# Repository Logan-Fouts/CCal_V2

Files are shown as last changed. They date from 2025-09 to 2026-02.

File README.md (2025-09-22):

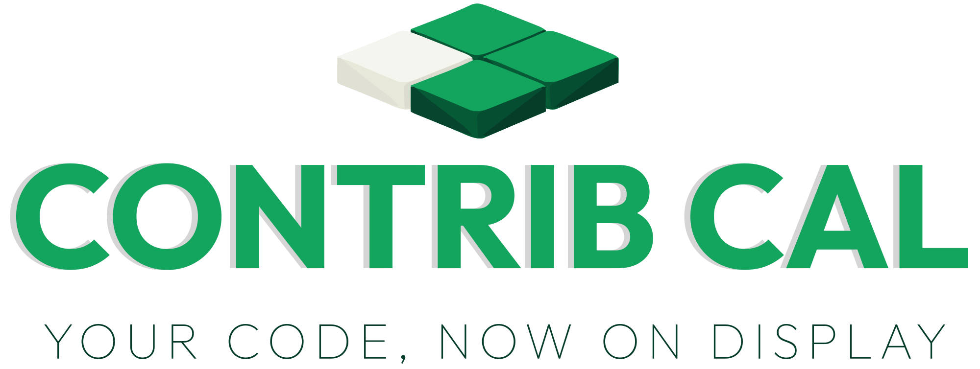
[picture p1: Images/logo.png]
  

Contrib Cal v2 is a contribution tracker built around a Raspberry Pi Zero W. It shows your GitHub activity using LEDs and includes a web interface for easy setup and control. The project is open, hackable, and designed for anyone interested in building their own contribution calendar.

Take a look at my [website!](https://www.contrib-cal.com/)

## Availability
This will soon be available to purchase as a kit from sellers like Elecrow and Tindie!

---

## Sponsored by PCBWay

PCBWay provided the PCBs for this project. They offer PCB fabrication and 3D printing with quick turnaround and worldwide shipping.  
[Check out PCBWay.com](https://pcbway.com) if you want to order your own boards.

---

## Features

- **GitHub Sync:** Shows your GitHub activity on an LED matrix.
- **Weather Animations:** Displays weather effects and temperature.
- **Tailscale:** Optionally connect your Pi to a Tailscale network.
- **Syncthing:** Optionally run a Syncthing node for file sync.
- **Pi-hole:** Optionally run Pi-hole for ad blocking.
- **Customizable:** Animations and logic are written in Python.
- **DIY Build:** Use a 3D-printed case and a custom PCB LED matrix.
- **Web Interface:** Configure settings and add-ons from your browser.

---

## Hardware Files

- **3D Print Files:** Available on Thingiverse at [https://www.thingiverse.com/thing:7136260](https://www.thingiverse.com/thing:7136260)
- **KiCad PCB Design Files:** Located in the `KiCad` folder in this repository.
- **PCBWay Order Zip:** The `PCBWay file.zip` in this repo can be uploaded directly to PCBWay—just drag and drop it on their site to order your board.

---

## Web Interface

You can manage most settings and add-ons through a simple web page hosted on the Pi.

---

## Build Guide

- **LEDs:** 28x SMD5050 RGB addressable LEDs (SK6812 or similar)
- **Microcontroller:** 1x Raspberry Pi Zero W (Pi Zero 2 W may work, but not tested)
- **Power Adapter:** 5V step down buck convertor and usbc breakout board
- **PCB:** Can be ordered using the `PCBWay file.zip` mentioned previosly

You can substitute

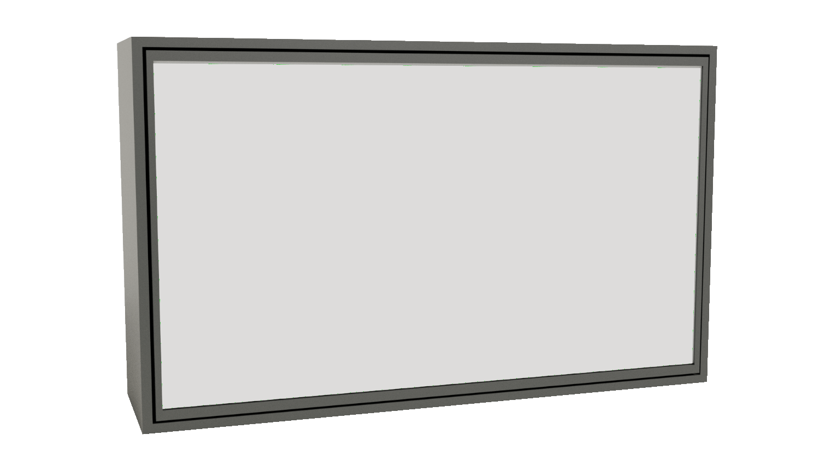
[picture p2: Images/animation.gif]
Contrib Cal in Action
  

---

## Getting Started

See [GettingStarted.md](./GettingStarted.md) for step-by-step instructions on flashing, setup, and configuration.

---

## Contributing

Pull requests and suggestions are welcome.  
If you run into issues or have ideas, feel free to open an issue on GitHub.

---

## Note on GitHub API Real-Time Updates

Contrib Cal v2 displays your GitHub activity as close to real-time as possible using the GitHub API. However, there may be delays in showing the most recent events due to how quickly GitHub updates and provides new event data. This is a limitation of the GitHub API itself and not an issue with this project's implementation.

---

Thanks for checking out Contrib Cal, Feel free to open up PRs!

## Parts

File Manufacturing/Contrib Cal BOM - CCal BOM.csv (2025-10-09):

Manufacturer Part Number | Qty | Original | Description | Purchase link
Main PCB | 1 | y | Main PCB | Produced by Elecrow.
TPS563201. | 1 | y | Buck Converter (Step-Down) WeAct Studio. Input: 5-36V, Output: 3.3V/2A | https://www.aliexpress.com/item/1005009680381342.html
Raspberry Pi Zero W | 1 | y | Raspberry Pi Zero W | https://www.alibaba.com/product-detail/Ras-Pberry-Pi-zero-W-Development_1601238061099.html
WS2812B (or SK6812) 5050 | 30 | n | SMD RGB LED WS2812B (or SK6812) 5050 package. IC built-in, 4-pin. | https://www.alibaba.com/product-detail/Promotion-Wholesale-IC-Buit-in-4pin_60610111946.html
Module-F55 | 1 | y | USB-C Breakout Board | https://www.alibaba.com/product-detail/YIXINTAI-USB-TYPE-C-conversion-board_1601234419325.html
Hookup Wire | 5 | n | ~12cm each. 28 AWG stranded wire is recommended for flexibility. Colors: Recommended (Red: 5V, Black: GND, other colors for data). | Elecrow to source.
Screw (M3 x 12mm) | 4 | n | Phillips, flat head. For securing the PCB assembly to the case. | Elecrow to source.
Heated Insert (M3) | 4 | n | Brass inserts to be melted into the 3D printed case for the M3 screws. | Elecrow to source.
Screw (M1.7) | 4 | n | Phillips, flat head. For mounting the Raspberry Pi Zero. | Elecrow to source.
Screw (M2.5) | 6 | n | Phillips, flat head. (Likely for the buck converter or other components). | Elecrow to source.
Screw (M2) | 2 | n | Phillips, flat head. (Likely for the USB-C breakout). | Elecrow to source.
Diffusion Paper / Screen | 1 | n | A5 size (210 x 148 mm), ~120 GSM weight. | https://www.alibaba.com/product-detail/Wholesale-120-g-350-g-C1S_1601258869224.html
microSD Card | 1 | n | 16GB+, Class 10. Major Brand Recommended (SanDisk, Samsung, Kingston). | Elecrow source. Do not source from random marketplaces due to high failure rate risk. Buy from a reputable electronics or computer store.
3D Printed Stencil Cut out | 1 | n | Print Settings: 0.2mm layers. | Produced by Elecrow as part of the PCB/Assembly order.
3D Printed Back Case | 1 | y | Print Settings: 0.2mm layers, Fuzzy Skin (Point Dist: 0.1mm, Thickness: 0.1mm on all walls). | Produced by Elecrow as part of the PCB/Assembly order.
3D Printed Front Face | 1 | y | Print Settings: 0.2mm layers, Fuzzy Skin, Enable Ironing for a smooth top surface. | Produced by Elecrow as part of the PCB/Assembly order.

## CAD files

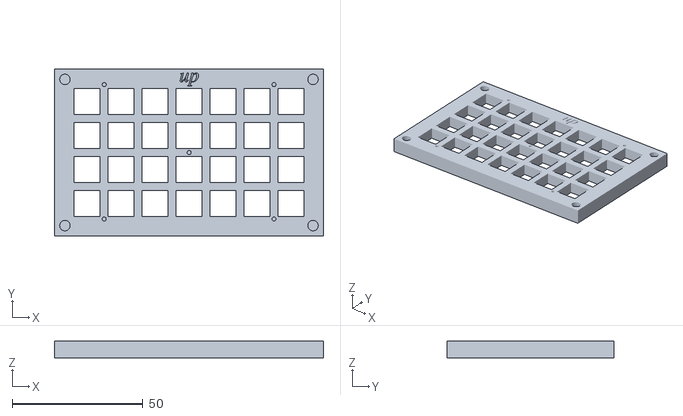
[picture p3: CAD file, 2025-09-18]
Hardware/FreeCAD/3d Objects/CCal v2-Face.obj
103.0 x 64.0 x 6.50

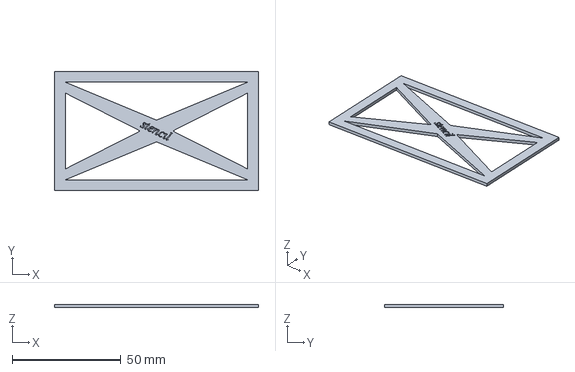
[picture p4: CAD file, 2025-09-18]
Hardware/FreeCAD/CCal v2.FCStd
94.0 x 55.0 x 1.50 mm

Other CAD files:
Hardware/FreeCAD/3d Objects/CCal v2-Cut Out Stencil v2.obj

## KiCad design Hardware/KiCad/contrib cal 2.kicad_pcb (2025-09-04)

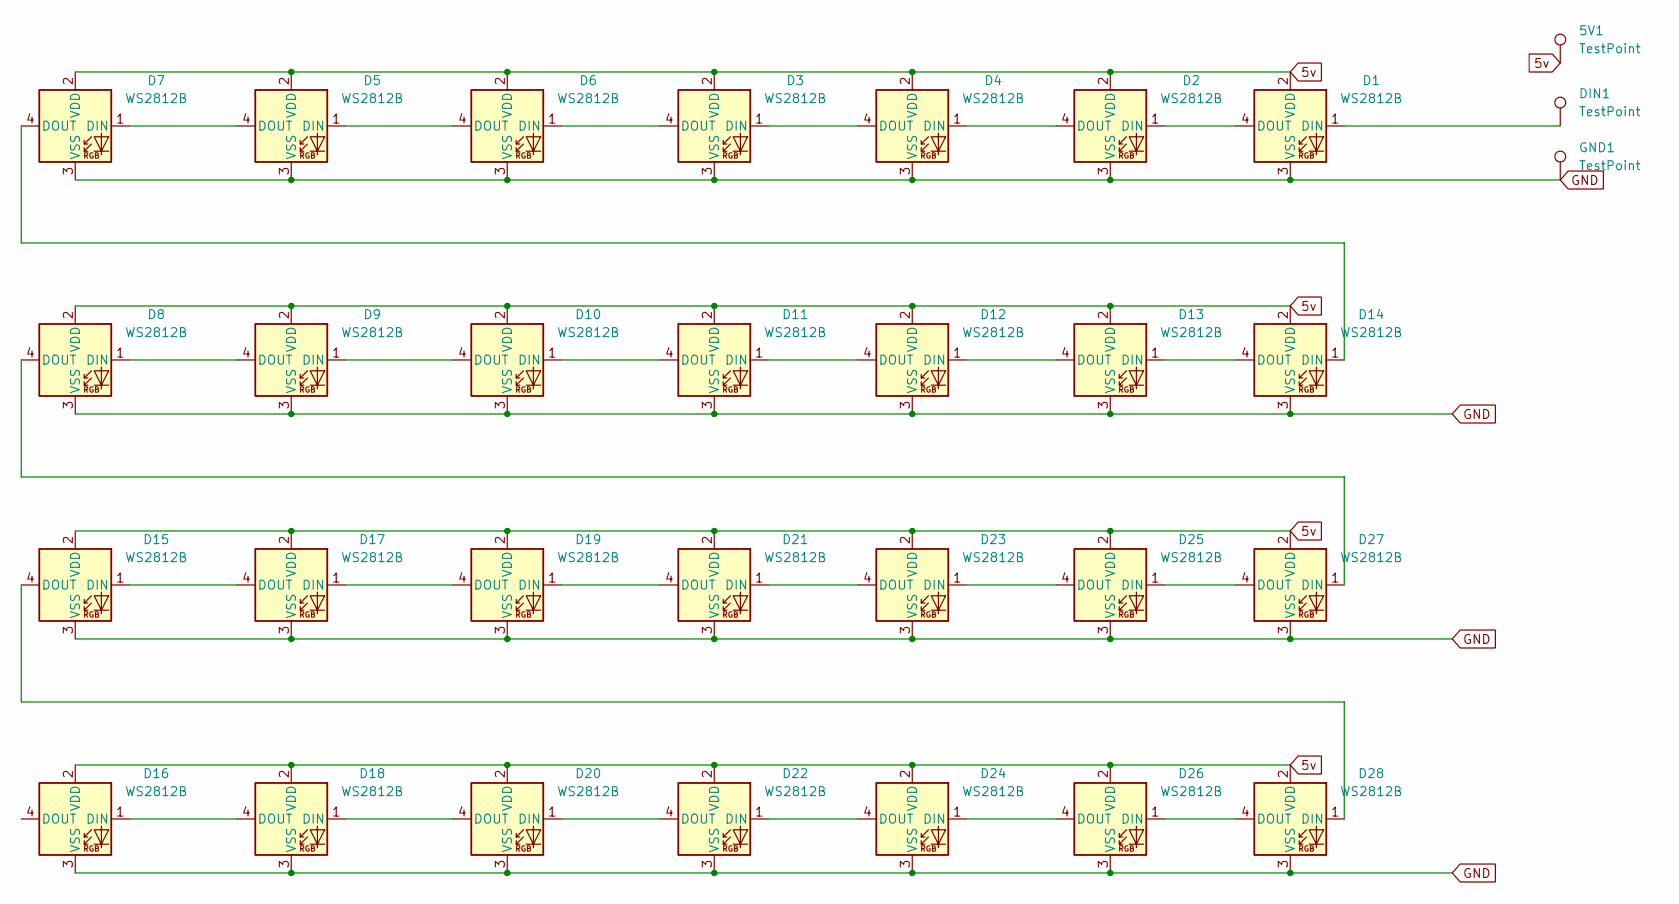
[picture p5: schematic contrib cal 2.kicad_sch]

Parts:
5V1: TestPoint; TestPoint_Pad_3.0x3.0mm
D1, D2, D3, D4, D5, D6, D7, D8, D9, D10, D11, D12, D13, D14, D15, D16, D17, D18, D19, D20, D21, D22, D23, D24, D25, D26, D27, D28: WS2812B; WS2812
DIN1: TestPoint; TestPoint_Pad_3.0x3.0mm
GND1: TestPoint; TestPoint_Pad_3.0x3.0mm

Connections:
5v: 5V1.1, D1.2 (VDD), D2.2 (VDD), D3.2 (VDD), D4.2 (VDD), D5.2 (VDD), D6.2 (VDD), D7.2 (VDD), D8.2 (VDD), D9.2 (VDD), D10.2 (VDD), D11.2 (VDD), D12.2 (VDD), D13.2 (VDD), D14.2 (VDD), D15.2 (VDD), D16.2 (VDD), D17.2 (VDD), D18.2 (VDD), D19.2 (VDD), D20.2 (VDD), D21.2 (VDD), D22.2 (VDD), D23.2 (VDD), D24.2 (VDD), D25.2 (VDD), D26.2 (VDD), D27.2 (VDD), D28.2 (VDD)
GND: D1.3 (VSS), D2.3 (VSS), D3.3 (VSS), D4.3 (VSS), D5.3 (VSS), D6.3 (VSS), D7.3 (VSS), D8.3 (VSS), D9.3 (VSS), D10.3 (VSS), D11.3 (VSS), D12.3 (VSS), D13.3 (VSS), D14.3 (VSS), D15.3 (VSS), D16.3 (VSS), D17.3 (VSS), D18.3 (VSS), D19.3 (VSS), D20.3 (VSS), D21.3 (VSS), D22.3 (VSS), D23.3 (VSS), D24.3 (VSS), D25.3 (VSS), D26.3 (VSS), D27.3 (VSS), D28.3 (VSS), GND1.1
unnamed: D1.1 (DIN), DIN1.1
unnamed: D1.4 (DOUT), D2.1 (DIN)
unnamed: D2.4 (DOUT), D4.1 (DIN)
unnamed: D3.1 (DIN), D4.4 (DOUT)
unnamed: D3.4 (DOUT), D6.1 (DIN)
unnamed: D5.1 (DIN), D6.4 (DOUT)
unnamed: D5.4 (DOUT), D7.1 (DIN)
unnamed: D8.1 (DIN), D9.4 (DOUT)
unnamed: D10.1 (DIN), D11.4 (DOUT)
unnamed: D9.1 (DIN), D10.4 (DOUT)
unnamed: D11.1 (DIN), D12.4 (DOUT)
unnamed: D12.1 (DIN), D13.4 (DOUT)
unnamed: D13.1 (DIN), D14.4 (DOUT)
unnamed: D7.4 (DOUT), D14.1 (DIN)
unnamed: D15.1 (DIN), D17.4 (DOUT)
unnamed: D15.4 (DOUT), D28.1 (DIN)
unnamed: D16.1 (DIN), D18.4 (DOUT)
unnamed: D17.1 (DIN), D19.4 (DOUT)
unnamed: D18.1 (DIN), D20.4 (DOUT)
unnamed: D19.1 (DIN), D21.4 (DOUT)
unnamed: D20.1 (DIN), D22.4 (DOUT)
unnamed: D21.1 (DIN), D23.4 (DOUT)
unnamed: D22.1 (DIN), D24.4 (DOUT)
unnamed: D23.1 (DIN), D25.4 (DOUT)
unnamed: D24.1 (DIN), D26.4 (DOUT)
unnamed: D25.1 (DIN), D27.4 (DOUT)
unnamed: D26.1 (DIN), D28.4 (DOUT)
unnamed: D8.4 (DOUT), D27.1 (DIN)

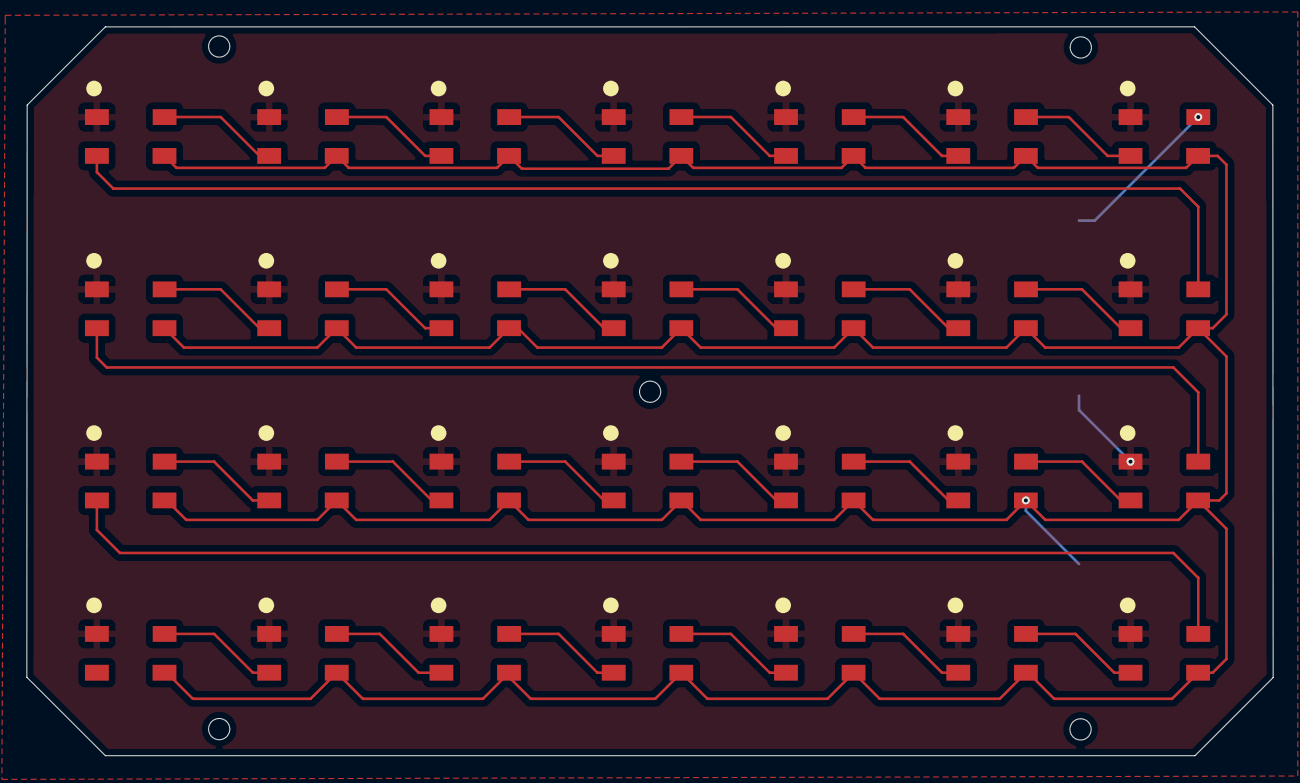
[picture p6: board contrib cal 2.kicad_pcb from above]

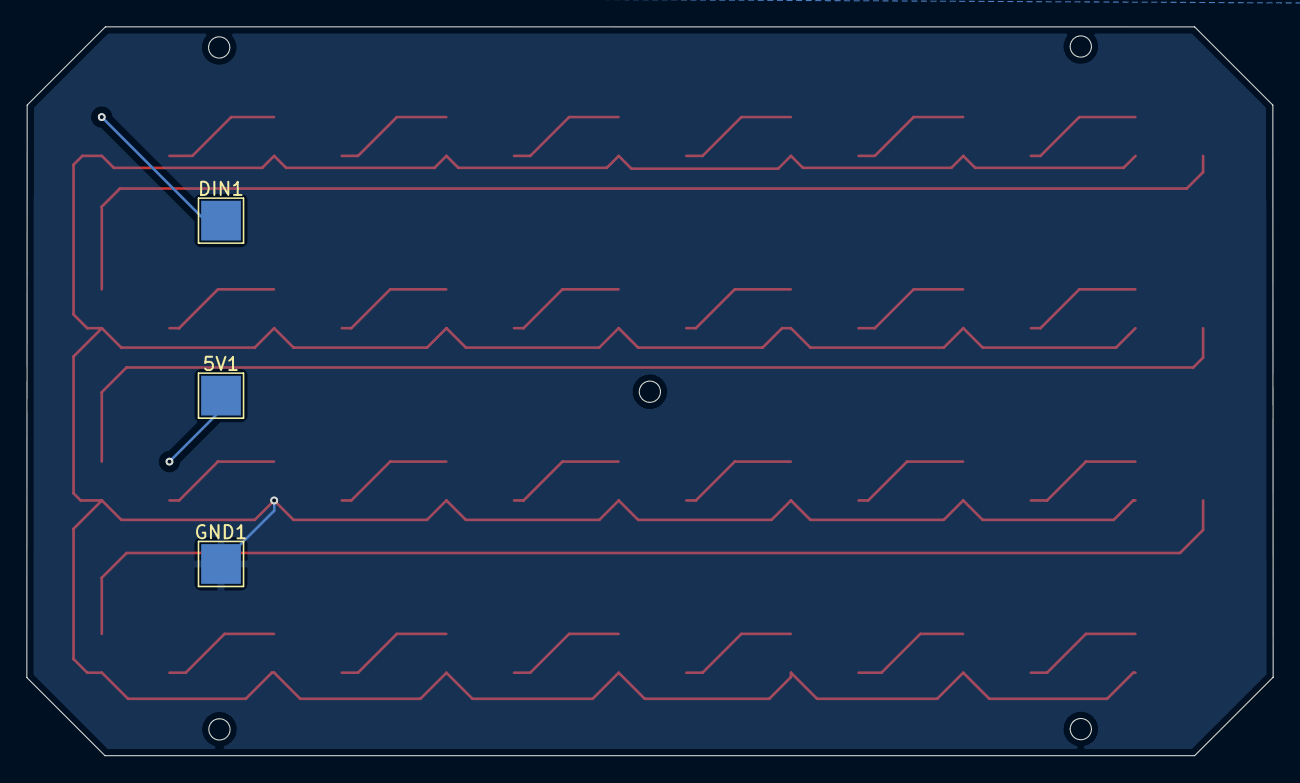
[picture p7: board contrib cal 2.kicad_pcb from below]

Board: 2 copper layers, 94.1 x 55.0 mm, 31 parts (3 on the bottom side), 30 nets.

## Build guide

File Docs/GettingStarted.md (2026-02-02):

# Getting Started with Daily Grid

This guide will help you set up your Daily Grid.  
Follow the steps below to get everything working.

---

## Quick Start (Prebuilt Image)

1. **Prepare Your SD Card**
    - Insert the micro SD card into your computer.
    - Open the **boot** partition on the SD card and locate the `wpa_supplicant.conf` file (if it does not exist, create it in the root of the boot partition).
    - Update these fields:
        - `country` — your country code (like US, GB, DE)
        - `ssid` — your WiFi network name
        - `psk` — your WiFi password

2. **Insert & Power On**
    - Safely eject the SD card and put it in your Pi Zero.
    - Power on the Pi and wait for it to connect to your network.
    - **Note:** The first boot can take a while as the Pi sets itself up and connects to WiFi. Be patient—it may take several minutes.
    - *(Tip: You can use the `ping` command to check when the device is online.)*

3. **Access the Web Interface**
    - Open a browser and go to:  
      `http://<device-ip>:8080`
    - Replace `<device-ip>` with your Pi's IP address.

4. **Configure Settings**
    - Log in with the default credentials below.
    - Use the web interface to finish setup.

---

### Default WebGUI Credentials

- **Username:** `dailygrid`
- **Password:** `raspberry`

---

### Set Your Own WebGUI Login

To set your own username and password for the WebGUI, run this command (replace `yourusername` and `yourpassword`):
```sh
echo -e "DAILYGRID_WEBGUI_USER=yourusername\nDAILYGRID_WEBGUI_PASS=yourpassword" > ~/Daily-Grid/WebGUI/.env
```
*Or just edit the file with whatever text editor you want*
You'll need to use sudo since the files are owned by the root user. You of course can modify the permisions so you dont need to use sudo.
```sh
sudo vim ~/Daily-Grid/WebGUI/.env
```

---

## Build Your Own

If you want to build Daily Grid yourself:

1. **Flash Raspbian**
    - Install the latest Raspbian OS on a Pi Zero W (using Pi Imager is recommended).

**Recommended:**  
Use [Raspberry Pi Imager](https://www.raspberrypi.com/software/) for the easiest setup.  
- Open Raspberry Pi Imager and select the OS (choose "Raspberry Pi OS Lite (32-bit)" or similar).
- Click the gear icon (⚙️) to set your username, password, WiFi info, and enable SSH.
- Write the image to your micro SD card.
- *(If you’re not using Pi Imager, you can manually edit or create the `wpa_supplicant.conf` file in the boot partition for WiFi setup.)* Take a look at step one from teh quick start above for more help.

2. **SSH into the pi**
    - Wait for it to connect to your wifi then ssh into the pi using the command below *(replace usrename and ip)*:
    ```sh
    ssh username@ip
    ```

3. **Download & Run the Setup Script**
    ```sh
    sudo curl https://raw.githubusercontent.com/Logan-Fouts/Daily-Grid/refs/heads/main/setup.sh | sh
    ```
    Or if you are having issues with the interactive shell then use the steps here:
    1. ```sh
       sudo wget https://raw.githubusercontent.com/Logan-Fouts/Daily-Grid/refs/heads/main/setup.sh
       ```
    2. ```sh
       sudo chmod +x setup.sh
       ```
    3. ```sh
       sudo ./setup.sh
       ```
    - **Note:** This command will take quite a while to run, as it installs all dependencies and sets up the system.

5. **Source the updated bashrc**
    - Either exit the ssh session then rejoin or run:
    ```sh
    source ~/.bashrc
    ```

4. **Configure Your Device**
    - Follow the Quick Start steps above starting at step 3.
    - If you enable Pi-hole during setup, the only thing you need to do is click through the Pi-hole options when prompted.

---

### Example `config.json`

Here’s an example configuration file you can use or edit:

```json
{
   "GITHUB_USERNAME": "Logan-Fouts",
   "GITHUB_TOKEN": "*",
   "STARTUP_ANIMATION": 3,
   "TAILSCALE_ENABLE": true,
   "PIHOLE_ENABLE": true,
   "SYNCTHING_ENABLE": true,
   "LAST_EVENT_ID": "*",
   "OPENWEATHERMAP_API_KEY": "*",
   "WEATHER_LAT": 0.000,
   "WEATHER_LON": 0.000,
   "BRIGHTNESS": 80
}
```

---

## Tips

- **Change your WebGUI password** after your first login.
- Make sure your Pi and your computer are on the same network.
- If you need help, open an issue on the [GitHub repository](https://github.com/Logan-Fouts/Daily-Grid).
- Be patient during the first boot and setup—some steps can take several minutes.

---

Thanks for trying out Daily Grid! Enjoy your new Activity Calendar.

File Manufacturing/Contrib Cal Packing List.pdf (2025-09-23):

# Packaging List: Contrib Cal V2 DIY Kit

## Instructions:

Place all items listed below into one main kit box. Small components (screws, inserts, LEDs) should be placed in separate, small bags. Electrostatic-sensitive items (PCB, Pi Zero, microSD) should be placed in anti-static bags.

Item | Component Name | Quantity | Packaging Notes
1 | Custom Main PCB | 1 Place in Anti-Static Bag
2 | Buck Converter (Step-Down) | 1 | Place in Anti-Static Bag or its original packaging.
3 | Raspberry Pi Zero W | 1 Place in Anti-Static Bag
4 | SMD RGB LED (WS2812B / SK6812) | 30 Bag all 30 LEDs together.
5 | USB-C Breakout Board | 1 | Place in Anti-Static Bag or its original packaging.
6 | Hook-up Wire (~12cm, 28 AWG) | 5 Bundle wires together or place in a small bag.
7 | 3D Printed Back Case | 1
8 | 3D Printed Front Face | 1
9 | Screw (M3 x 12mm) | 4 Place in a small bag labeled M3x12mm Screws
10 | Heated Insert (M3, Brass) | 4 Place in a small bag labeled M3 Inserts
11 | Screw (M1.7) | 4 Place in a small bag labeled M1.7 Screws
12 | Screw (M2.5) | 6 Place in a small bag labeled M2.5 Screws
13 | Screw (M2) | 2 Place in a small bag labeled M2 Screws
14 | Diffusion Paper / Screen (A5, ~120GSM) | 1 Place flat in the box. Do not crease
15 | microSD Card (16GB+, Class 10) | 1 Place in Anti-Static Bag or its original packaging.

## Kit Packer Verification:

All items above are present.
All bags are sealed and correctly labeled.
Anti-static protection is used for sensitive components. Main kit box is sealed.

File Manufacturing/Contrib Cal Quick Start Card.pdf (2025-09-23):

# Contrib Cal V2 DIY Kit

## You'll Need:

- Soldering iron & solder
- Phillips screwdrivers (sizes for M1.7, M2, M2.5, M3)
- Computer with microSD card reader

## Get Started:

1. Scan the QR code below or visit: https://www.contrib-cal.com/
2. Follow the complete step-by-step video or written assembly guide online.

## Need Help?

Visit: https://github.com/Logan-Fouts/CCal_V2/issues or email: logan-electronics@proton.me

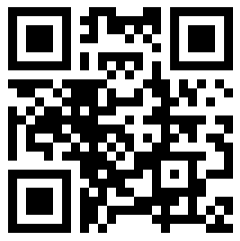
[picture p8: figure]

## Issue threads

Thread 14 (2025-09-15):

Finalized Case

Logan-Fouts, 2025-09-15:
- [x] **Print a fully final case and include instructions maybe in the print like orientation indicators fuzzy skin with new PEI plate**
- [x] **Take better photos**
- [x] **Update images everywhere**
- [ ] **Make new assembly video**

Closed 2025-09-29.

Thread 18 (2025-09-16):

BCD for Temps

Logan-Fouts, 2025-09-16:
## Binary Coded Decimals (BCD)
In order to show temps better or at least differently on such a small display maybe allowing for a Binary coded decimal system could be nice.
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

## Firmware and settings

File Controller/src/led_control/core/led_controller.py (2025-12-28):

import board
import neopixel
from typing import List, Tuple, Optional


class LEDController:
    """Low-level hardware interface for NeoPixel LEDs."""

    def __init__(self, pin_num: int = 18, num_leds: int = 28, brightness: float = 1.0):
        self.num_leds = num_leds
        self.brightness = max(0.0, min(1.0, float(brightness)))

        if -1 < pin_num < 28:
            gpio_pin = getattr(board, f"D{pin_num}")

        self.strip = neopixel.NeoPixel(
            gpio_pin,
            self.num_leds,
            brightness=1.0,
            auto_write=False,
            pixel_order=neopixel.GRB,
        )

    def display_number(self, number, color=(255, 255, 255)):
        """Display a number using predefined digit patterns."""
        digit_patterns = {
            0: [4, 5, 6, 11, 13, 18, 20, 25, 26, 27],
            1: [6, 5, 12, 19, 26, 27, 25],
            2: [4, 5, 6, 11, 19, 25, 26, 27],
            3: [4, 5, 6, 12, 18, 26, 27],
            4: [6, 4, 11, 13, 18, 25, 12],
            5: [6, 13, 5, 4, 18, 25, 26, 27],
            6: [6, 13, 20, 27, 12, 26, 11, 18, 25],
            7: [6, 5, 4, 11, 19, 27],
            8: [4, 5, 6, 11, 13, 18, 20, 25, 26, 27, 19],
            9: [6, 5, 4, 11, 18, 25, 19, 20, 13],
        }
    
        # Handle negative temperature
        if number < 0:
            number = abs(number)  # Use absolute value
            color = (128, 0, 128)  # Dark purple color for negative temps
    
        str_num = str(number).zfill(2)[-2:]  # Ensure two digits
    
        # Display first digit
        first_digit = int(str_num[0])
        for idx in digit_patterns.get(first_digit, []):
            if 0 <= idx < self.num_leds:
                self.set_pixel(idx, color)
    
        # Display second digit (offset by -4)
        second_digit = int(str_num[1])
        for idx in digit_patterns.get(second_digit, []):
            idx2 = idx - 4
            if 0 <= idx2 < self.num_leds:
                self.set_pixel(idx2, color)

    def _apply_brightness(
        self, color: Tuple[int, int, int], brightness: Optional[float] = None
    ) -> Tuple[int, int, int]:
        """Apply brightness scaling to a color tuple."""
        if brightness is None:
            brightness = self.brightness
        brightness = max(0.0, min(1.0, float(brightness)))
        return tuple(int(c * brightness) for c in color)

    def set_pixel(
        self, idx: int, color: Tuple[int, int, int], brightness: Optional[float] = None
    ):
        """Set a single LED to a color with optional brightness."""
        if 0 <= idx < self.num_leds:
            color = self._apply_brightness(color, brightness)
            self.strip[idx] = color

    def set_pixels(
        self, pixels: List[Tuple[int, int, int]], brightness: Optional[float] = None
    ):
        """Set multiple LEDs at once."""
        for i, color in enumerate(pixels):
            if i < self.num_leds:
                self.set_pixel(i, color, brightness)

    def fill(self, color: Tuple[int, int, int], brightness: Optional[float] = None):
        """Fill all LEDs with a color and optional brightness."""
        color = self._apply_brightness(color, brightness)
        self.strip.fill(color)

    def show(self):
        """Update the LED strip with current colors."""
        self.strip.show()

    def turn_all_off(self):
        """Turn off all LEDs."""
        self.strip.fill((0, 0, 0))
        self.strip.show()

    def cleanup(self):
        """Clean up resources."""
        self.turn_all_off()

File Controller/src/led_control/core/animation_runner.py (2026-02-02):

import math
import random
import time
from typing import Tuple, Optional
from led_control.core.led_controller import LEDController


class AnimationRunner:
    """Runs various LED animations using LED controller."""

    def __init__(self, led_controller: LEDController):
        self.led = led_controller
        self.num_leds = led_controller.num_leds

    def display_number(
        self, number: int, color: Tuple[int, int, int] = (255, 255, 255)
    ):
        """Display a number using the LED controller."""
        self.led.display_number(number, color)
        self.led.show()

    def turn_all_off(self):
        """Turn off all LEDs."""
        self.led.turn_all_off()

    def sun_animation_loop(self, end_time: float, brightness: Optional[float] = None):
        """Run sun animation until end_time."""
        colors = [(255, 255, 0), (255, 255, 50), (255, 255, 20)]
        ray_pattern = [0, 1, 2] * ((self.num_leds // 3) + 1)

        while time.time() < end_time:
            cycle_time = time.time()
            cycle_progress = (cycle_time % 2) / 2
            core_brightness = 0.3 + 0.7 * (
                0.5 + 0.5 * math.sin(cycle_progress * math.pi)
            )
            wave_pos = int(cycle_progress * 3) % 3

            for i in range(self.num_leds):
                dist_from_center = abs(i - self.num_leds // 2)
                color_idx = ray_pattern[i]
                wave_effect = (3 - (dist_from_center + wave_pos) % 3) * 0.3
                led_brightness = min(1.0, core_brightness + wave_effect)
                self.led.set_pixel(
                    i,
                    colors[color_idx],
                    brightness * led_brightness if brightness else led_brightness,
                )

            self.led.show()
            time.sleep(0.05)

    def cloud_animation_loop(self, end_time: float, brightness: Optional[float] = None):
        """Run cloud animation until end_time."""
        cloud_colors = [(180, 180, 180), (220, 220, 220), (255, 255, 255)]
        cloud = [12, 11, 20, 19, 18, 17]

        self.turn_all_off()
        while time.time() < end_time:
            for i in range(0, 4):
                for pixel in cloud:
                    led_index = pixel - i
                    if 0 <= led_index < self.num_leds:
                        self.led.set_pixel(led_index, cloud_colors[0], brightness)
                self.led.show()
                time.sleep(0.5)
                self.turn_all_off()

    def rain_animation_loop(
        self,
        end_time: float,
        speed: float = 1.0,
        drop_chance: float = 0.4,
        brightness: Optional[float] = None,
    ):
        """Run rain animation until end_time."""
        rain_colors = [(0, 128, 255), (0, 0, 255)]
        rows = 4
        cols = self.num_leds // rows
        if self.num_leds % rows != 0:
            cols += 1
        drops = []

        while time.time() < end_time:
            self.turn_all_off()
            if random.random() < drop_chance:
                new_col = random.randint(0, cols - 1)
                drop_brightness = (
                    random.uniform(brightness * 0.6, brightness * 0.9)
                    if brightness
                    else random.uniform(0.6, 0.9)
                )
                drops.append(
                    {
                        "row": 0,
                        "col": new_col,
                        "speed": speed,
                        "color": random.choice(rain_colors),
                        "brightness": drop_brightness,
                    }
                )

            for drop in drops[:]:
                led_index = drop["col"] + (int(drop["row"]) * cols)
                if 0 <= led_index < self.num_leds:
                    self.led.set_pixel(led_index, drop["color"], drop["brightness"])
                drop["row"] += drop["speed"]
                if drop["row"] >= rows:
                    drops.remove(drop)

            self.led.show()
            time.sleep(0.1)

    def snow_animation_loop(
        self,
        end_time: float,
        speed: float = 0.5,
        drop_chance: float = 0.3,
        brightness: Optional[float] = None,
    ):
        """Run snow animation until end_time."""
        snow_colors = [
            (255, 255, 255),  # white (G,R,B)
            (220, 200, 255),  # light blueish (G,R,B)
            (240, 220, 255),  # lighter blueish (G,R,B)
        ]

        rows = 4
        cols = self.num_leds // rows
        if self.num_leds % rows != 0:
            cols += 1
        drops = []

        while time.time() < end_time:
            self.turn_all_off()
            if random.random() < drop_chance:
                new_col = random.randint(0, cols - 1)
                drop_brightness = (
                    random.uniform(brightness * 0.6, brightness * 0.9)
                    if brightness
                    else random.uniform(0.6, 0.9)
                )
                drops.append(
                    {
                        "row": 0,
                        "col": new_col,
                        "speed": speed,
                        "color": random.choice(snow_colors),
                        "brightness": drop_brightness,
                    }
                )

            for drop in drops[:]:
                led_index = drop["col"] + (int(drop["row"]) * cols)
                if 0 <= led_index < self.num_leds:
                    self.led.set_pixel(led_index, drop["color"], drop["brightness"])
                drop["row"] += drop["speed"]
                if drop["row"] >= rows:
                    drops.remove(drop)

            self.led.show()
            time.sleep(0.1)

    def thunderstorm_animation_loop(
        self, end_time: float, brightness: Optional[float] = None
    ):
        """Run thunderstorm animation until end_time."""
        rain_colors = [(0, 128, 255), (0, 0, 255), (0, 128, 255)]
        rows = 4
        cols = self.num_leds // rows
        drops = []
        last_lightning = time.time()

        while time.time() < end_time:
            self.turn_all_off()
            if random.random() < 0.7:
                new_col = random.randint(0, cols - 1)
                drop_brightness = (
                    random.uniform(brightness * 0.6, brightness * 0.9)
                    if brightness
                    else random.uniform(0.6, 0.9)
                )
                drops.append(
                    {
                        "row": 0,
                        "col": new_col,
                        "speed": 1.0,
                        "color": random.choice(rain_colors),
                        "brightness": drop_brightness,
                    }
                )
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

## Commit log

2025-06-27 Web GUI Config and led control rewrite start
2025-06-27 update to use correct config for led controls
    [config_manager.py]
2025-06-28 reduce sleep duration in main loop to 1 minute for more frequent LED updates. New readme
2025-07-03 Add new event fetching and flashing functionality to GitHub tracker and LED utilities
2025-07-07 Api start and led update optimizations
2025-07-10 Add LED display for temperature and enhance weather tracking functionality
2025-08-29 Add temporary password setup for Pi-hole installation
2025-08-29 Clarify instructions for configuring the device in the Getting Started guide
2025-08-29 Fix setup script to use sudo for Pi-hole password setup and run setup_addons.sh with proper command
2025-08-29 Fix config file path in CONFIG_MANAGER and update USERNAME variable in main.py
    [config_manager.py]
2025-09-01 Update temperature color thresholds and change default event color in main.py
2025-09-02 Refactor LED brightness handling and update GUI to include brightness input
2025-09-02 Add handling to skip LED updates when brightness is set to 0
2025-09-04 Added in hardware files and updated readme
    [contrib cal 2.kicad_pcb, contrib cal 2.kicad_sch]
2025-09-09 Add time-based condition to skip LED updates and define ON_TIME/OFF_TIME constants
2025-09-09 Add ON_TIME and OFF_TIME configuration options for LED control
2025-09-15 Add unit tests for LED control, weather tracking, and GitHub event handling; refactor setup script
2025-09-16 Remove brightness parameter from sun_animation_loop call in LedUtils
2025-09-16 Tuen off leds during specific times
2025-09-16 Fix digit pattern for number 3 in led_utils.py
2025-09-16 Enhance LED animations and add weather tracker tests
    - Updated snow animation colors to use GRB order for consistency.
    - Improved fog animation with gradient effects and multiple moving patches.
    - Refactored brightness handling in snow and rain animations.
    - Added unit tests for WeatherTracker, covering various scenarios including cache handling and API requests.
2025-09-16 Enhance theater chase animation and update LED demo script
2025-09-16 Refine LED control logic to respect on_time and off_time settings
2025-09-18 Add demo script for LED control and comprehensive tests for WeatherTracker
    - Created a demo script (led_demo.py) showcasing number display, color fills, and various animations using LedUtils.
    - Implemented unit tests for WeatherTracker, covering weather updates, API requests, and cache management.
    - Added mock data and methods to simulate API responses and test error handling in weather requests.
    [CCal v2-Buck Converter.obj, CCal v2-Cut Out Stencil v2.obj, CCal v2-Face.obj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]
2025-09-18 remove unneeded 3d files
    [CCal v2-Buck Converter.obj, CCal v2-usbc breakout.obj, Pi_Zero_W.stl]
2025-09-19 Refactor LED control and animation modules with comprehensive tests
    - Implemented AnimationRunner class for various LED animations.
    - Created LEDController class for low-level hardware interaction.
    - Added utility functions for color manipulation in led_utils.
    - Developed unit tests for AnimationRunner and LEDController.
    - Enhanced test coverage for utility functions in led_utils.
    - Introduced configuration management for GitHub and weather integrations.
2025-09-19 Refactor weather tracker API URL and enhance LED display functionality for temperature indication
2025-09-19 Refactor LED control main script and GitHubTracker integration; update username handling in setup script
2025-09-19 Enhance animation handling and brightness control in LED updates
2025-09-19 Refactor LED control configuration and improve brightness handling; update setup script for correct directory paths
    [animation_runner.py, config_manager.py]
2025-09-20 # Cleanup ## Did the following - Fixed brightness implementation for calandar - Added demo script to show possibilities
    [animation_runner.py]
2025-09-23 Elecrow files
    [Contrib Cal BOM - CCal BOM.csv]
2025-09-23 updated bom and case obj
    [Contrib Cal BOM - CCal BOM.csv]
2025-09-23 updated case obj
2025-10-09 update BOM
    [Contrib Cal BOM - CCal BOM.csv]
2025-12-28 Implement negative temperature handling in LED controller
    Add handling for negative temperature values with a specific color.
2026-01-20 fix: Adjust current day initialization and add metric field to tracker configurations
